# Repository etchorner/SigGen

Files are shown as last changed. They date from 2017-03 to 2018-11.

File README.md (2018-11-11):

# Description:
SigGen is a very basic implementation of a one channel signal generator, which I needed 
to come up with in order to finish building a 40 meter direct conversion receiver. The code in this repository is for the 
Arduino Micro which makes up the brains of this little test gear project.

This project uses an Arduino microcontroller to manage an Si5351 Clock Generator which is capable of generating RF signals 
from 8 kHz to about 160 Mhz. The output is a square wave 3Vpp signal with selectable drive levels from 2 mA to 8 mA. A 
four row by twenty column LCD is part of the user interface. Both the LCD and the Si5351 modules are controlled and 
monitored through the I2C bus presented by the Arduino controller. The final piece of the system, as of 1/14/2015, is a rotary encoder with push-button which is used to operate the signal generator system.

In large part, this project would be a dead ender were it not for the work of Jason Milldrum, [NT7S](http://nt7s.com/), from whose Si5351Arduino [library](https://github.com/etherkit/Si5351Arduino) my accomplishment springs. This library stands well above anything else I've seen in terms of ease of use and reliability. 

## Operation
If wired according to the Nano pins indicated in the code, one can change the tuning rate, or tuning steps, by pushing the encoder axial push-button. The rate will decrement from the most significant digit (10 MHz) to the least (1 Hz), at which point the rate will 'wrap-around to the most significant digit again.

To tune or alter the output frequency, rotate the encoder. The frequency will increase as the encoder is rotated clockwise and decrease when rotated counter-clockwise. The rate of frequency change is a result of the tuning rate you select; if the rate is set to '1 Hz', each detent in the encoder will raise or lower the output by 1 Hz.

The output can be taken via coaxial or other shielded cable or can be connected to an antenna. In the prototype system, it has been used to troubleshoot and align a direct conversion receiver, successfully, with a twelve inch length of insulated wire acting as an antenna.

## CHANGELOG
**1/14/2015, v0.1, Initial Operating Capability (IOC)**
* One (of three) output channels active, set to 8 mA drive, all others off).
* User can select tuning rates, in discrete digit steps from 1 Hz to 10 Mhz, using rotary encoder pushbutton.
* User can change output frequency by rotating rotary encoder; CW rotation for increment, CCW for decrement.
* Frequency changes are in the tuning rate digit selected by the user and accumulate properly.

## TODO:
- [ ] Fix tuning rate/step skipping (Issue SigGen#1) 
- [ ] Add EEPROM or other NVRAM method of storing last sets (freq, tune rate, and drive) at power off
- [ ] {HARDWARE}Implement step attenuator on output to give precise dbm level outpus. May involve code to control switching mechanism (relay, pin diodes, other?).
- [ ] Change UI frequency readout to add thousands and millions seperator commas.

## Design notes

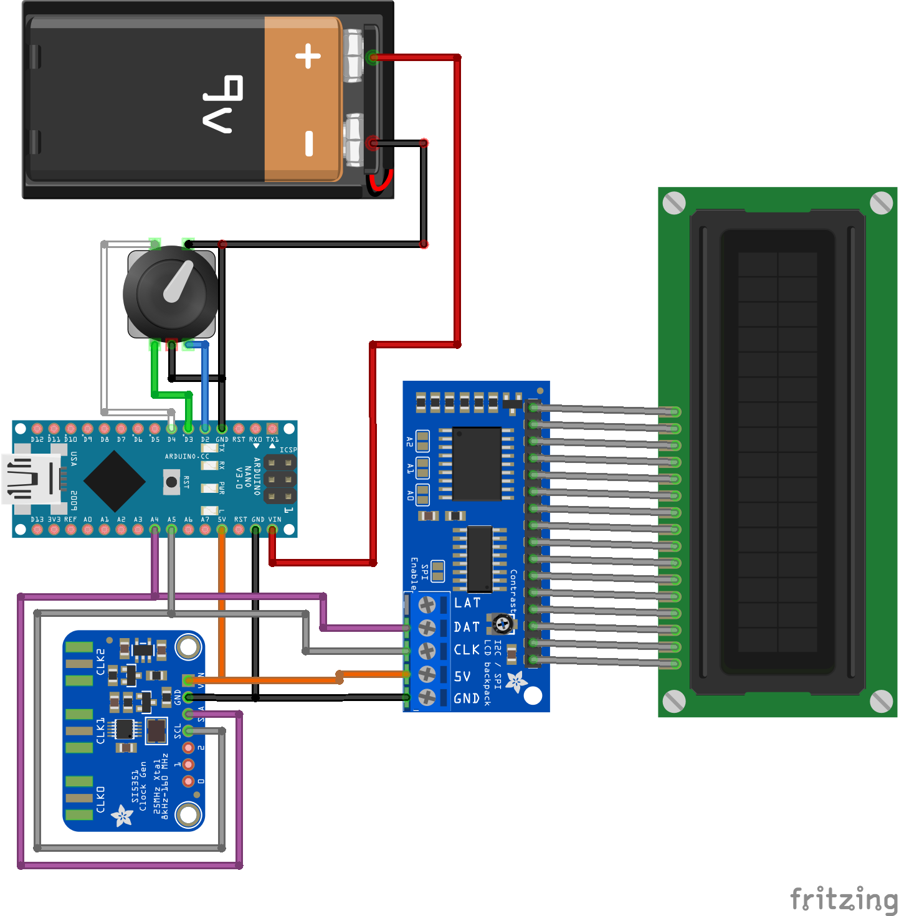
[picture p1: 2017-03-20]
SigGen_bb.png

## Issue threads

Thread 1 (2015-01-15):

Skipped tune rates

etchorner, 2015-01-15:
When pushing the rotary encoder push-button to change tuning rates, the cursor should move from left to right until the end is reached (LSD) at which point the cursor should wrap around to the opposite end of the array (MSD).

From time to time, the cursor will jump one or more positions in the array. The cursor location in the array and the index into the tuning rate remain synchronized, but doesn't obey the "one click one step" design pattern.

Suspect subtle timing issue in the switch reading conditionals or some capacitor debouncing will be needed on the hardware side.

dandav56, 2019-07-06:
Hi,
I have built this , looked quite good and easy...
Every thing is the same ,  but doesnt update the screen frequency, cursor moved correctly
However , I can not get the encoder to work with this software, can you help?

Thanks
Daniel

etchorner, 2019-07-07:
Daniel,

It's hard to say why this isn't working for you, not being able to see your code. One likely culprit is that the interrupts are failing on you, because you may not have wired the encoder on the correct pins for your Arduino type. Take a look at the website for the Encoder library I use in this project (https://www.pjrc.com/teensy/td_libs_Encoder.html ) which has details about pins permitted for encoders on each Arduino type.

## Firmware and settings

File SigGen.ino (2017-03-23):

/**

  SigGen.ino - RF Signal Generator Control System

  Copyright (C) 2015 Christopher M. Horner, chris.horner@gmail.com

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
 **/
#define ENCODER_OPTIMIZE_INTERRUPTS
#include <Encoder.h>
#include <Bounce2.h>
#include <Wire.h>
#include <si5351.h>
#include <LiquidCrystal_I2C.h>

// LCD/I2C parameter variables
#define i2cAddr 0x27
// Rotary Encoder parameter variables
#define encPinA 2  // Nano pin D2
#define encPinB 3 // Nano pin D3
#define encPinSw 4  // Nano pin D4
// Other Variables - cleanup?
int dfindex = 4;
int pos = 19 - dfindex;
const long deltaF[] = { 1, 10, 100, 1000, 10000, 100000, 1000000, 10000000 }; // scaling factors for freq adjustment
const String tuneRate[] = { "1 Hz   ", "10 Hz  ", "100 Hz ", "1 kHz  ", "10 kHz ", "100 kHz", "1 MHz  ", "10 MHz "};
unsigned long freq = 7190000; // TODO: why is this double and not long?
unsigned long stop = 73000000;

// Create the objects
LiquidCrystal_I2C lcd(i2cAddr, 20, 4);
Encoder encoder = Encoder(encPinA, encPinB);
Si5351 si5351;
Bounce debouncer = Bounce();

void setup() {
  // set up LCD and blank display
  lcd.init();
  lcd.init();
  lcd.backlight();
  lcd.home();

  // set up I/O pins (NOTE: rotary encoder pins are handled in the Encoder library)
  pinMode(encPinSw, INPUT_PULLUP);
  debouncer.attach(encPinSw);
  debouncer.interval(5);

  // setup the si5351 generator
  si5351.init(SI5351_CRYSTAL_LOAD_10PF, 0, 0); // 10pf for the Adafruit si5351 modules, uses ABM8G-25.000MHZ-B4Y-T or ABM8G-25.000MHZ-4Y-T3
  si5351.drive_strength(SI5351_CLK0, SI5351_DRIVE_8MA);
  si5351.set_freq(freq * SI5351_FREQ_MULT, SI5351_CLK0);

  // generate/terminate signals
  si5351.output_enable(SI5351_CLK0, 1);  // turn on desired output
  si5351.set_clock_pwr(SI5351_CLK1, 0);  // disable unused outputs
  si5351.set_clock_pwr(SI5351_CLK2, 0);  // disable unused outputs

  // test display setup
  lcd.print("SigGen v1.0 CLK0");
  lcd.setCursor(0, 1);       // go to the 2nd line
  lcd.print("Drive: 8 mA");
  lcd.setCursor(0, 2);        // go to the third line
  lcd.print("Tune Rate : ");
  ; // start data at (10,2)
  lcd.print(tuneRate[dfindex]);
  lcd.setCursor(0, 3); // go to 4th line
  changeFreq();
  lcd.setCursor(pos, 3);
  lcd.cursor();
}

void loop() {
  // handle rotary encoder axial switch in the main code loop.
  if (debouncer.update()) { // don't bother if nothing has changed...
    if (debouncer.fell()) {  // don't bother if it hasn't gone LOW....
      // decrement the frequency change index for each click
      dfindex--;

      // wrap around from end to beginning
      if (dfindex < 0)
        dfindex = 7;

      // cursor position and set the debounce variable.
      pos = 19 - dfindex;

      // change tune rate display accordingly
      lcd.setCursor(12, 2);
      lcd.print(tuneRate[dfindex]);
      lcd.setCursor(pos, 3);
    }
  }
  // change freq according to the Encoder accumulation, if any
  freq = freq + (encoder.read() * deltaF[dfindex]);
  changeFreq();
  encoder.write(0);
}

void changeFreq() {
  // change the output first
  si5351.set_freq(freq * SI5351_FREQ_MULT, SI5351_CLK0);
  String freqStr = String(freq, DEC);

  // blank the line
  lcd.setCursor(12, 3);
  lcd.print("       ");
  lcd.setCursor(0, 3);
  lcd.print("Freq: ");

  // handle the various sizes of "freq"
  if (freq >= 10000000) {
    lcd.setCursor(12, 3);
    lcd.print(freq);
  } else {
    if (freq < 1000000) {
      lcd.setCursor(14, 3);
      lcd.print(freq);
    } else {
      lcd.setCursor(13, 3);
      lcd.print(freq);
    }
  }

  // establish the cursor position
  pos = 19 - dfindex;
  lcd.setCursor(pos, 3);

}

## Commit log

2017-01-09 Update SigGen.ino
    - Changes to LCD/I2C library changed some setup and usage code.
    - Changes to Etherkit Si5351 library changed some setup and usage code.
    - Changed from Micro to Nano, so changed some pinouts and moved the rotary encoder interrupt.
2017-01-11 Fritzing stuff
    Fritizing file for the SigGen project, with PNG of the wiring.
    [SigGen.fzz]
2017-03-20 Schematic Fixes
    Corrected the error in rotary encoder connections.
    [SigGen.fzz]
2017-03-21 Code cleanup and library changes
    - Replaced awkware encoder debouncing logic with the Bounce2 library.
    - Replaced standard Rotary library with more responsive Encoder
    library...with built in interrupts!
    - changed some "const" values to defines...like the compiler won't
    inline them to #defines any way, and my old "C" ass likes #defines
    better.
    - Since the Encoder library bakes in the interrupts for me, I ditched
    the crappy ISR and hateful bit-fiddling for interrupt service in the
    main code.
    [SigGen.ino]
2017-03-21 Bug Fix - frequency change unreachable
    BUG FIX: Managed to put the call to change frequency inside the section
    of conditional that only runs when the encoder pushbutton is pressed.
    Since this is an extremely infrequent UI event, the signal generator
    would seem completely unresponsive, until the button is pressed, at
    which point an ungodly large number of accumulated frequency change
    counts will execute.
    [SigGen.ino]
2017-03-23 Code cleanup
    - changed the set_freq() calls to match the 0.01Hz resolution that NT7S
    snuck in the library (need live test on RX). The code here tracks the
    frequency in a UL, exactly matching the integer frequency in Hz, but the
    set_freq() method expects integer values expanded by two orders of
    magnitude. Multiplying by SI5351_FREQ_MULT saves us from the trap.

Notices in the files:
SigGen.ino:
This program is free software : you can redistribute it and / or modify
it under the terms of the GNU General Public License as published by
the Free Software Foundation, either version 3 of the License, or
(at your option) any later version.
